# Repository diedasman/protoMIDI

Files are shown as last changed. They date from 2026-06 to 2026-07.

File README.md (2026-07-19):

# protoMIDI

## Sponsor

**THIS PROJECT IS SPONSORED BY [PCBWAY](https://www.pcbway.com/)**

protoMIDI is a compact DIY HID macropad with the control language of a small
MIDI controller. The current v1.1 design uses a custom PCB in a two-piece
enclosure with eight illuminated push buttons, two rotary encoders, a toggle,
a small utility push button, and an nRF52840 Pro Micro style controller.

> **Asset version:** The screenshots, renders, photographs, and GIFs in
> [`assets/`](./assets/) currently show v1.0 hardware. Updated v1.1 assets will
> be added later.

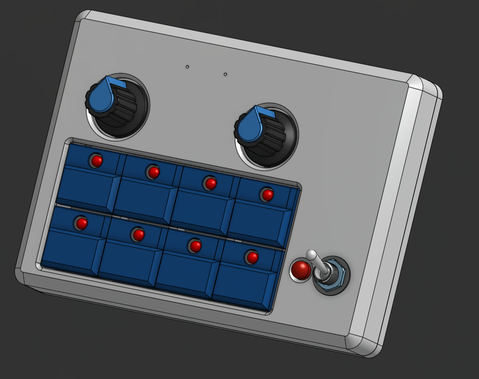
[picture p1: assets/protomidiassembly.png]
protoMIDI v1.0 assembly reference


Despite the controller-style hardware, protoMIDI currently targets ZMK keyboard
firmware. It presents as a keyboard/HID macropad, not as a USB MIDI or BLE MIDI
controller. DAW, transport, clip, track, or effects labels are keymap choices,
not a dedicated MIDI protocol layer.

## Status

v1.1 is the active design. Both manufacturing handoffs remain available:

| Version | Status | DFM pack |
| --- | --- | --- |
| v1.1 | Current | [hardware/protoMIDI-DFM-PACK-v1.1](./hardware/protoMIDI-DFM-PACK-v1.1/README.md) |
| v1.0 | Historical release | [hardware/protoMIDI-DFM-PACK-v1.0](./hardware/protoMIDI-DFM-PACK-v1.0/README.md) |

The Rev A prototype remains in [prototype](./prototype/README.md) as historical
reference for the earlier display-equipped build.

## v1.1 Update

v1.1 retains the v1.0 control layout and updates the manufacturing files:

- PCB silkscreen refinements and newly exported v1.1 Gerbers
- Increased enclosure wall thickness
- Increased USB-C connector clearance
- Increased switch clearance
- A slight angle added to the bottom enclosure
- A supported v1.1 ZMK firmware build with ZMK Studio over USB

The design scope remains:

- Custom PCB as the main electronics artifact
- 8x PB86-B1 illuminated momentary switches
- 2x EC11/PEC11R style rotary encoders with knobs
- 1x MTS-style toggle switch
- 1x 6 mm utility push button
- 1x nRF52840 Pro Micro style controller
- 1x single-cell LiPo battery connection
- Two-piece enclosure: top and bottom
- M2.5 mounting hardware with threaded inserts, matched to the CAD references

The local KiCad source folder, `hardware/protoMIDI-KiCAD/`, and local CAD
reference folder, `hardware/CAD/`, are intentionally ignored. The tracked
manufacturing handoffs are the versioned DFM packs.

## Images

All project-owned images below are v1.0 references.

| Bare PCB | PCB assembly |
| --- | --- |
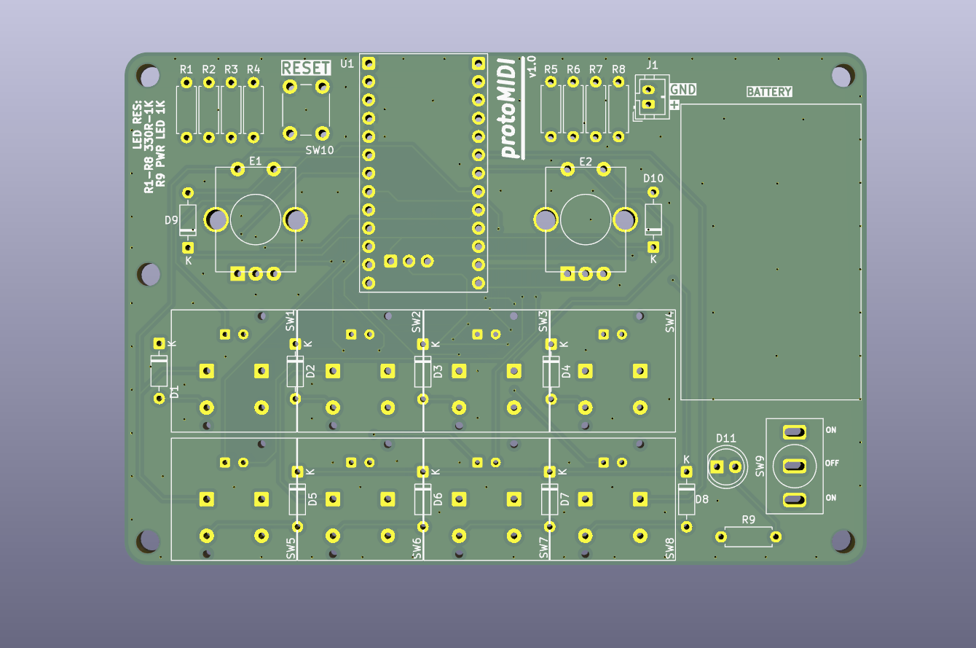
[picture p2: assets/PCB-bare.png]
protoMIDI v1.0 bare PCB
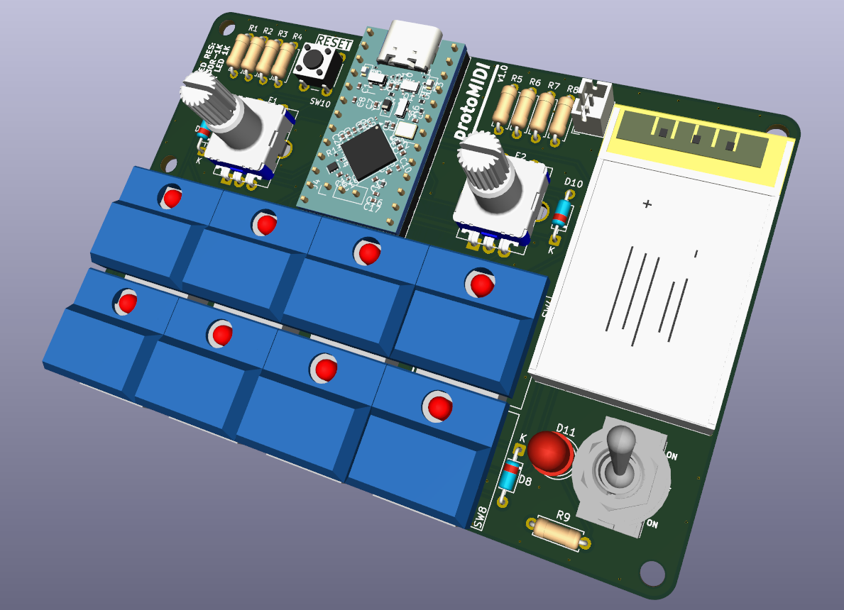
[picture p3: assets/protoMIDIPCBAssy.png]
protoMIDI v1.0 PCB assembly
|  |  |

| Front assembly | Back assembly |
| --- | --- |
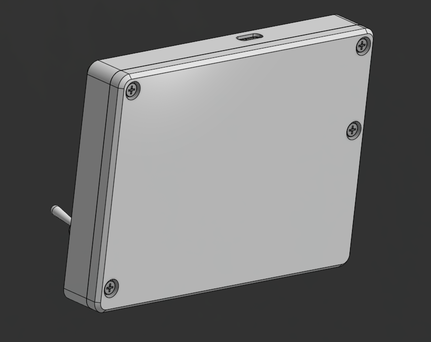
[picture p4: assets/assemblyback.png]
protoMIDI v1.0 back assembly
| protoMIDI v1.0 assembly |  |

| Front exploded view | Back exploded view |
| --- | --- |
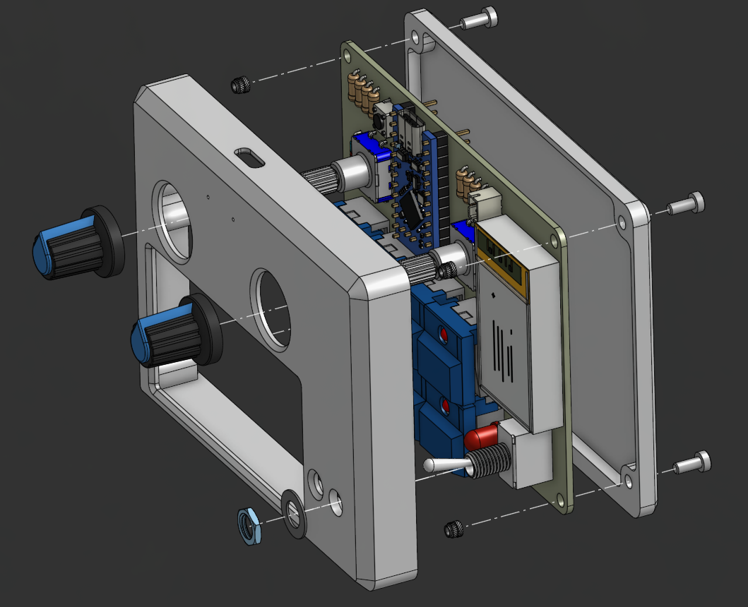
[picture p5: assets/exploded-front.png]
protoMIDI v1.0 front exploded view
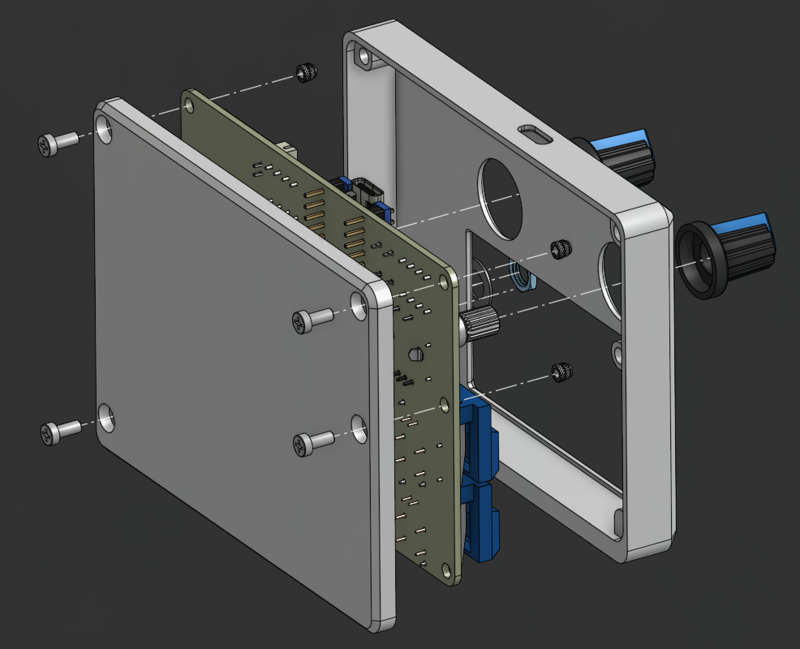
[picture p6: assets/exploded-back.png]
protoMIDI v1.0 back exploded view
|  |  |

Prototype media lives in [prototype](./prototype/README.md):

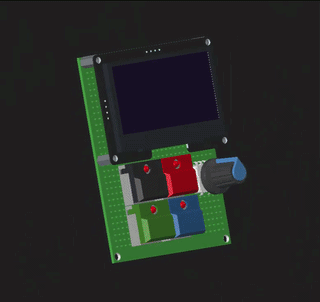
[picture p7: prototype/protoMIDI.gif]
protoMIDI prototype demo


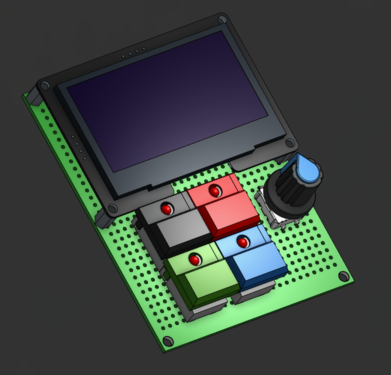
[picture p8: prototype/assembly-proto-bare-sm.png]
protoMIDI prototype assembly


## Hardware

Start with [hardware/README.md](./hardware/README.md) for version differences,
tracked exports, ignored source folders, and DFM pack links. Component source
notes live in [resources](./resources/README.md).

## Firmware

The supported v1.1 firmware lives in [firmware](./firmware/README.md). It targets
the `nice_nano_v2` compatible nRF52840 board and `protomidi` shield, includes
both encoders and all eight PB86 switches, and supports live keymap editing in
ZMK Studio over USB. The repository intentionally ships only this Studio build.

Build it from the repository root:

```sh
./firmware/build-local.sh
```

The ignored output is:

```text
firmware/build-out/protomidi-v1.1-studio-usb.uf2
```

The Rev A display-equipped firmware remains available in
[prototype/firmware](./prototype/firmware/README.md).

## Repository Layout

```text
assets/       Project-owned v1.0 visual references (v1.1 update pending)
firmware/     Supported v1.1 USB Studio ZMK build
hardware/     Versioned v1.0 and v1.1 DFM handoffs and hardware notes
prototype/    Rev A prototype firmware, CAD export, preview image, and demo GIF
resources/    Source references and component notes
```

Local-only ignored working areas:

```text
hardware/protoMIDI-KiCAD/     Active KiCad design source and BOM CSV
hardware/CAD/                 Local CAD assemblies and reference exports
firmware/builds/standard/     Optional local-only non-Studio configuration
firmware/build-out/           Firmware build output
prototype/firmware/build-out/ Prototype firmware build output
```

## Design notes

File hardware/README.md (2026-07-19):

# protoMIDI Hardware

This directory documents the protoMIDI custom PCB and two-piece enclosure. v1.1
is the current release; the original v1.0 manufacturing handoff remains
available for reproducibility.

## Manufacturing Handoffs

| Version | Status | Contents |
| --- | --- | --- |
| [v1.1 DFM pack](./protoMIDI-DFM-PACK-v1.1/README.md) | Current | v1.1 PCB Gerbers/drills and revised enclosure STEP/STL exports |
| [v1.0 DFM pack](./protoMIDI-DFM-PACK-v1.0/README.md) | Historical | Original PCB Gerbers/drills, enclosure STEP/STL exports, and top drawing DXF |

The packs are deliberately versioned rather than replacing the earlier
manufacturing release.

## v1.1 Changes

- Refined PCB silkscreen and exported a new v1.1 Gerber set
- Increased enclosure wall thickness
- Increased clearance around the USB-C connector
- Increased switch clearance
- Added a slight angle to the bottom enclosure
- Promoted the ZMK Studio USB firmware to the supported v1.1 build

## Hardware Scope

- Custom PCB with nRF52840 Pro Micro style controller footprint
- 8x PB86-B1 illuminated push buttons
- 2x EC11/PEC11R style rotary encoders
- 2x encoder knobs, referenced in the local enclosure assembly CAD
- 1x MTS-style toggle switch
- 1x 6 mm utility push button
- 1x LiPo battery connector
- Two-piece enclosure: top and bottom
- M2.5 mounting hardware with threaded inserts, referenced by the local CAD

The OLED display is prototype-only and is not part of v1.0 or v1.1.

## BOM

The electronic BOM is common to v1.0 and v1.1. Mechanical items are added from
the enclosure/CAD design. Copies of this table live in both DFM pack READMEs.

`R1-R8` are the illuminated switch LED current-limit resistors. `R9` is the
power/status LED current-limit resistor for `D11`.

| Qty | References | Value / Part | Description |
| ---: | --- | --- | --- |
| 1 | BT1 | Battery_Cell | Single-cell LiPo battery, KiCad footprint `Battery_LiPo_802540_800mAh` |
| 10 | D1-D10 | 1N4148 | Signal diodes for switch matrix |
| 1 | D11 | LED | 5 mm power/status indicator LED |
| 2 | E1,E2 | PEC11R-4215F-S0024 | EC11/PEC11R style vertical rotary encoders, 15 mm shaft |
| 1 | J1 | JST PH 1x02 | 2-pin vertical battery connector, 2.00 mm pitch |
| 8 | R1-R8 | 330 ohm | Through-hole resistors for illuminated switch LEDs |
| 1 | R9 | 680 ohm to 1 kOhm | Through-hole resistor for power/status LED `D11` |
| 8 | SW1-SW8 | PB86-B1 | Illuminated momentary push buttons |
| 1 | SW9 | SW_DPDT_x2 / MTS style | Vertical toggle switch |
| 1 | SW10 | SW_Push | 6 x 6 mm utility push button |
| 1 | U1 | nRF ProMicro | nRF52840 Pro Micro style controller module |
| 2 | ENC knobs | ROTARY_ENCODER_KNOB | Encoder knobs; see the local versioned enclosure assembly in `hardware/CAD/` for fit/details |
| 1 | Enclosure top | protoMIDI ENCLOSURE TOP | STEP/STL export in the selected versioned DFM pack |
| 1 | Enclosure bottom | protoMIDI ENCLOSURE BOTTOM | STEP/STL export in the selected versioned DFM pack |
| 4 | Mounting screws | EDDT-M2.5-L6 | M2.5 L6 screw reference; local CAD file `hardware/CAD/EDDT-M2.5-L6.step` |
| 4 | Threaded inserts | EMLZ-M2.5-L3 | M2.5 L3 threaded insert reference; local CAD file `hardware/CAD/EMLZ-M2.5-L3.step` |

## Media

> **Asset version:** The following project images show v1.0. They have not yet
> been regenerated for the v1.1 enclosure and silkscreen updates.

protoMIDI v1.0 PCB assembly

protoMIDI v1.0 bare PCB

protoMIDI v1.0 front exploded enclosure view

protoMIDI v1.0 back exploded enclosure view

## Source Boundary

The active KiCad source in `hardware/protoMIDI-KiCAD/` and CAD references in
`hardware/CAD/` are local working files and intentionally ignored. The tracked
public handoffs are the versioned DFM packs above.

## Prototype Reference

The Rev A prototype remains available for comparison:

- [Prototype overview](../prototype/README.md)
- [Prototype firmware](../prototype/firmware/README.md)
- [Prototype STEP assembly](../prototype/CAD/protoMIDI%20ASSEMBLY.step)

Prototype assembly preview

Prototype demo GIF

## Component References

Useful component notes remain in [resources](../resources/README.md). Some notes
are historical prototype references; the display page is not part of v1.0 or
v1.1.

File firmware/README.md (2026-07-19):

# protoMIDI v1.1 Firmware

This directory contains the supported protoMIDI v1.1 ZMK firmware. It targets
the nRF52840 Pro Micro-compatible `nice_nano_v2` board and the `protomidi`
shield. The custom PCB has no display.

The supported build includes live keymap editing through ZMK Studio over USB.
VIA is a QMK configurator and is not used by this ZMK project.

Only the `studio-usb` configuration is included in the repository. The original
non-Studio configuration is intentionally local-only and excluded by
`.gitignore`, so the public firmware has one supported version.

## Build and Flash

From the repository root, run:

```sh
./firmware/build-local.sh
```

The script builds only the supported Studio configuration and writes one
ignored UF2 file:

```text
firmware/build-out/protomidi-v1.1-studio-usb.uf2
```

The script uses the official ZMK Docker build image. The first build downloads
the ZMK and Zephyr dependencies into the ignored `firmware/.zmk/` workspace;
later builds reuse that workspace.

Double-tap reset on the controller to enter its UF2 bootloader, then copy the
UF2 file onto the mounted bootloader drive.

## USB Keymap Editing

Flash `protomidi-v1.1-studio-usb.uf2`, connect protoMIDI over USB, and open
[ZMK Studio](https://zmk.studio/) in Chrome/Edge or its native app. This build
starts Studio unlocked because configuration access already requires a physical
USB connection.

Studio can edit the two encoder push switches and the eight illuminated push
buttons. Encoder rotation remains defined in `protomidi.keymap`, matching ZMK
Studio's current encoder limitation.

The tracked source configuration lives in:

```text
firmware/builds/studio-usb/config/
```

## PCB Pinout

The switch matrix is `col2row`.

| Signal | nRF52840 GPIO |
| --- | --- |
| ROW0, ROW1, ROW2 | P1.01, P1.02, P1.07 |
| COL0, COL1, COL2, COL3 | P0.02, P1.11, P0.29, P0.31 |
| ENC1 A, B | P1.15, P1.13 |
| ENC2 A, B | P0.10, P0.09 |
| LED1-LED8 | P0.17, P0.20, P0.22, P0.24, P1.00, P0.11, P1.04, P1.06 |

The LEDs run in four vertical pairs: LED1+LED5, LED2+LED6, LED3+LED7, and
LED4+LED8. Each pair is on for 250 ms, giving a one-second chase, followed by
one second with all LEDs off before the chase restarts.

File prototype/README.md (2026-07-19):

# protoMIDI Prototype

This folder contains the Rev A protoMIDI prototype. It is the earlier
display-equipped build used to prove the physical controls, ZMK firmware, CAD
assembly, and HID behavior before the v1.0 custom PCB release.

The prototype is historical reference. The active design is v1.1 in
[../hardware](../hardware/README.md).

protoMIDI prototype demo

## Contents

| Path | Purpose |
| --- | --- |
| [firmware](./firmware/README.md) | ZMK user config and local build script for the Rev A prototype |
| [CAD/protoMIDI ASSEMBLY.step](./CAD/protoMIDI%20ASSEMBLY.step) | Exported STEP assembly for the bare prototype build |
| [assembly-proto-bare-sm.png](./assembly-proto-bare-sm.png) | Prototype assembly preview image |
| [protoMIDI.gif](./protoMIDI.gif) | Prototype demo media used by older docs |

## Prototype Hardware

The Rev A prototype uses:

- nRF52840 Pro Micro style development board compatible with `nice_nano_v2`
- Four PB86-B1 illuminated momentary switches
- One EC11-style rotary encoder with push switch
- 2.42 inch 128x64 SSD1309 I2C OLED display
- 3.7 V LiPo battery
- ZMK firmware configured as a HID keyboard/macropad

The PB86 LEDs are hardwired to 3V3 in the prototype. Firmware does not dim them,
turn them off individually, or represent per-button LED state.

protoMIDI prototype assembly

## Firmware

Build from the repository root:

```sh
./prototype/firmware/build-local.sh
```

The default firmware output is ignored and written to:

```text
prototype/firmware/build-out/protomidi-nice_nano_v2.uf2
```

Double-tap reset on the nRF52840 board to enter the UF2 bootloader, then copy the
generated `.uf2` file to the mounted bootloader drive.

See [prototype/firmware/README.md](./firmware/README.md) for firmware details,
dependencies, pinout notes, and manual build commands.

## Relationship To v1.1

The v1.0 release removed the display, moved to a custom PCB, increased the
switch count to eight, increased the encoder count to two, and added tracked
enclosure DFM exports. v1.1 refines that PCB silkscreen and enclosure and adds
the supported ZMK Studio firmware build. Use this folder for old behavior checks
and migration comparisons.

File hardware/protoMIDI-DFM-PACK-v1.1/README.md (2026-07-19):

# protoMIDI v1.1 DFM Pack

This folder is the current manufacturing handoff for protoMIDI. It contains the
v1.1 PCB fabrication files and revised two-piece enclosure exports. The
[v1.0 DFM pack](../protoMIDI-DFM-PACK-v1.0/README.md) remains available as the
original release.

## v1.1 Changes

- Refined PCB silkscreen and exported a new Gerber set
- Increased enclosure wall thickness
- Increased USB-C connector clearance
- Increased switch clearance
- Added a slight angle to the bottom enclosure

The supported firmware paired with this release is the
[v1.1 ZMK Studio USB build](../../firmware/README.md).

## Files

| Path | Contents |
| --- | --- |
| [PCB-GERBERS](./PCB-GERBERS/) | v1.1 PCB copper, mask, paste, silkscreen, edge cuts, PTH drill, and NPTH drill files |
| [ENCLOSURE](./ENCLOSURE/) | Revised enclosure top and bottom as STEP and STL |

Enclosure exports:

- [protoMIDI ENCLOSURE TOP v1.1.step](./ENCLOSURE/protoMIDI%20ENCLOSURE%20TOP%20v1.1.step)
- [protoMIDI ENCLOSURE TOP v1.1.stl](./ENCLOSURE/protoMIDI%20ENCLOSURE%20TOP%20v1.1.stl)
- [protoMIDI ENCLOSURE BOTTOM v1.1.step](./ENCLOSURE/protoMIDI%20ENCLOSURE%20BOTTOM%20v1.1.step)
- [protoMIDI ENCLOSURE BOTTOM v1.1.stl](./ENCLOSURE/protoMIDI%20ENCLOSURE%20BOTTOM%20v1.1.stl)

The KiCad source project and local CAD reference files remain ignored in
`hardware/protoMIDI-KiCAD/` and `hardware/CAD/`.

## BOM

The electronic BOM is unchanged from v1.0; v1.1 changes the PCB silkscreen and
enclosure geometry.

| Qty | References | Value / Part | Description |
| ---: | --- | --- | --- |
| 1 | BT1 | Battery_Cell | Single-cell LiPo battery, KiCad footprint `Battery_LiPo_802540_800mAh` |
| 10 | D1-D10 | 1N4148 | Signal diodes for switch matrix |
| 1 | D11 | LED | 5 mm power/status indicator LED |
| 2 | E1,E2 | PEC11R-4215F-S0024 | EC11/PEC11R style vertical rotary encoders, 15 mm shaft |
| 1 | J1 | JST PH 1x02 | 2-pin vertical battery connector, 2.00 mm pitch |
| 8 | R1-R8 | 330 ohm | Through-hole resistors for illuminated switch LEDs |
| 1 | R9 | 680 ohm to 1 kOhm | Through-hole resistor for power/status LED `D11` |
| 8 | SW1-SW8 | PB86-B1 | Illuminated momentary push buttons |
| 1 | SW9 | SW_DPDT_x2 / MTS style | Vertical toggle switch |
| 1 | SW10 | SW_Push | 6 x 6 mm utility push button |
| 1 | U1 | nRF ProMicro | nRF52840 Pro Micro style controller module |
| 2 | ENC knobs | ROTARY_ENCODER_KNOB | Encoder knobs; see local v1.1 CAD assembly for fit/details |
| 1 | Enclosure top | protoMIDI ENCLOSURE TOP v1.1 | Revised STEP/STL export in `ENCLOSURE/` |
| 1 | Enclosure bottom | protoMIDI ENCLOSURE BOTTOM v1.1 | Revised STEP/STL export in `ENCLOSURE/` |
| 4 | Mounting screws | EDDT-M2.5-L6 | M2.5 L6 screw reference |
| 4 | Threaded inserts | EMLZ-M2.5-L3 | M2.5 L3 threaded insert reference |

## Visual References

> **Asset version:** The repository images currently show v1.0. They are useful
> as general assembly references but do not show the v1.1 silkscreen or
> enclosure geometry. Updated screenshots will be added later.

protoMIDI v1.0 assembly reference

protoMIDI v1.0 PCB assembly reference

protoMIDI v1.0 exploded enclosure reference

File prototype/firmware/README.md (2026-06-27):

# protoMIDI Firmware

This directory is a nested ZMK user config inside the larger protoMIDI hardware
repo. The preferred build path is local, so builders can compile firmware from
the open-source files in this repository entirely on their own machine.

## Table of Contents

- [Hardware Support](#hardware-support)
- [Pinout](#pinout)
- [Quick Build](#quick-build)
- [Dependencies](#dependencies)
- [Manual Build Sketch](#manual-build-sketch)

The firmware target is the Rev A bare controller:

- Board: `nice_nano_v2`
- Shield: `protomidi`
- Inputs: 2x3 key matrix with five populated positions
- Encoder: one EC11-compatible quadrature encoder
- Display: 2.42 inch 128x64 SSD1309 OLED over I2C using Zephyr's SSD1306-compatible driver

## Hardware Support

This build is the protoMIDI firmware baseline: switches, encoder, OLED display,
USB HID, and Bluetooth HID. Pin assignments match the Rev A pinout documented
below.

Supported:

- `nice_nano_v2` compatible nRF52840 board target
- 2x3 GPIO switch matrix
- Four PB86 momentary buttons
- Encoder push switch as the fifth matrix key
- One unused matrix position at row 1, column 2
- `col2row` matrix diode direction
- EC11-style rotary encoder on separate A/B GPIOs
- 128x64 SSD1309 OLED on I2C
- Custom animated monochrome protoMIDI OLED graphic
- USB HID keyboard
- Bluetooth HID keyboard through the selected ZMK board target
- UF2 firmware output for drag-and-drop flashing

Default key behavior:

| Control | Binding |
| --- | --- |
| PB86-1 | Play/pause |
| PB86-2 | none |
| PB86-3 | Previous track |
| PB86-4 | Next track |
| Encoder push | Mute |
| Encoder clockwise | Volume up |
| Encoder counter-clockwise | Volume down |

The PB86 LEDs are hardwired to 3V3. Firmware does not provide LED/backlight or
per-button LED state control.

The OLED pin choice is intentional for this build: the shield overrides the
`nice_nano_v2` I2C defaults and places the SSD1309 module on `P1.06`/`P1.04`.

## Pinout

This is the firmware pinout for the Rev A bare controller.

ZMK target:

- Board target: `nice_nano_v2`
- Shield: `protomidi`
- Firmware path: `prototype/firmware/config/boards/shields/protomidi`

Matrix diode direction: `col2row`

| Matrix position | Function | GPIO label | ZMK devicetree pin |
| --- | --- | --- | --- |
| Row 0 | PB86-1/PB86-2 encoder push row | `115` | `&gpio1 15` |
| Row 1 | PB86-3/PB86-4 row | `011` | `&gpio0 11` |
| Col 0 | PB86-1/PB86-3 | `002` | `&gpio0 02` |
| Col 1 | PB86-2/PB86-4/unused column | `111` | `&gpio1 11` |
| Col 2 | Encoder push column | `029` | `&gpio0 29` |

Logical matrix:

| | COL0 | COL1 | COL2 |
| --- | --- | --- | --- |
| ROW0 | PB86-1 | PB86-2 | ENC_PUSH |
| ROW1 | PB86-3 | PB86-4 | unused |

Encoder:

| Function | GPIO label | ZMK devicetree pin |
| --- | --- | --- |
| Encoder A | `024` | `&gpio0 24` |
| Encoder B | `022` | `&gpio0 22` |
| Encoder common | GND | GND |

OLED display:

| Function | GPIO label | ZMK devicetree pin |
| --- | --- | --- |
| OLED SDA | `106` | `NRF_PSEL(TWIM_SDA, 1, 6)` |
| OLED SCL | `104` | `NRF_PSEL(TWIM_SCL, 1, 4)` |

The shield overlay overrides the `nice_nano_v2` I2C defaults and uses
`P1.06`/`P1.04` for the OLED.

## Quick Build

Install Docker, then run this from the repository root:

```sh
./prototype/firmware/build-local.sh
```

The default output path is:

```text
prototype/firmware/build-out/protomidi-nice_nano_v2.uf2
```

Double-tap reset on the nRF52840 board to enter the UF2 bootloader, then copy
that `.uf2` file to the mounted bootloader drive.

The build script also accepts explicit board and shield arguments:

```sh
./prototype/firmware/build-local.sh nice_nano_v2 protomidi
```

The script keeps the ZMK checkout in `prototype/firmware/.zmk/workspace`, which
is ignored by git. The first run downloads the ZMK and Zephyr dependencies, so
it can take a while. Later runs reuse that workspace.

## Dependencies

Default path:

- Docker
- Internet access for dependency downloads

The script uses the official `zmkfirmware/zmk-build-arm:stable` container image,
so builders do not need to install Zephyr SDK, `west`, or Python packages on the
host system.

## Manual Build Sketch

If you already maintain your own ZMK/Zephyr toolchain, build with:

```sh
west build -s zmk/app -b nice_nano_v2 -- \
  -DSHIELD=protomidi \
  -DZMK_CONFIG=/absolute/path/to/protoMIDI/prototype/firmware/config
```

The build command above matches the tracked `nice_nano_v2` and `protomidi`
configuration.

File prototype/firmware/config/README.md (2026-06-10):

# ZMK Config

## Table of Contents

- [Configuration](#configuration)
- [Files](#files)

`boards/shields/protomidi` contains the protoMIDI shield definition.

## Configuration

- The controller uses ZMK's `nice_nano_v2` board target.
- Pin labels in the hardware docs are nRF GPIO labels: `002` means `P0.02`,
  `115` means `P1.15`, and so on.
- Matrix diode direction is `col2row`.
- OLED display support is enabled through Zephyr's SSD1306-compatible driver for
  the 128x64 SSD1309 module.
- PB86 LED/backlight and per-button LED state control are not configured because
  the PB86 LEDs are hardwired to 3V3.

## Files

- `boards/shields/protomidi/protomidi.overlay`
- `boards/shields/protomidi/protomidi.keymap`
- `boards/shields/protomidi/protomidi.conf`
- `boards/shields/protomidi/custom_status_screen.c`
- `west.yml`

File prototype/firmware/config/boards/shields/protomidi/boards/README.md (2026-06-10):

# Board-Specific Overlay Directory

## Table of Contents

- [Purpose](#purpose)
- [Tracked Board Target](#tracked-board-target)

## Purpose

This directory is available for board-specific shield overlays. The tracked Rev
A build uses the base `protomidi.overlay` file in the parent shield directory.

## Tracked Board Target

The firmware build target is `nice_nano_v2`. The base shield overlay uses direct
nRF GPIO controller references so the pinout remains easy to compare with the
physical board silkscreen.

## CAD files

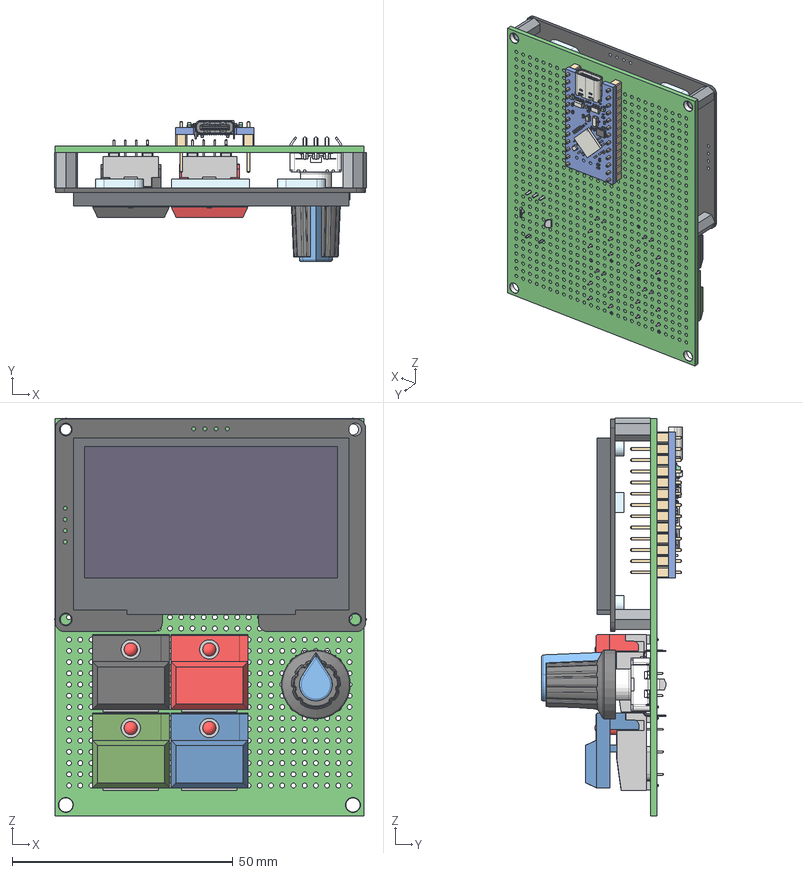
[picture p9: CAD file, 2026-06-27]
prototype/CAD/protoMIDI ASSEMBLY.step
70.7 x 32.0 x 90.1 mm
C_0402_1005Metric_14
USB_C_Receptacle_GCT_USB4105-xx-A_16P_TopMnt_Horizontal030
R_0201_0603Metric_6
SOT-23
USB_C_Receptacle_GCT_USB4105-xx-A_16P_TopMnt_Horizontal
C_0402_1005Metric_3
L_0402_1005Metric_1
Adafruit PB86-1AR v003
L_0402_1005Metric_3
USB_C_Receptacle_GCT_USB4105-xx-A_16P_TopMnt_Horizontal025
Adafruit PB86-1AR v1
USB_C_Receptacle_GCT_USB4105-xx-A_16P_TopMnt_Horizontal020
ROTARY_ENCODER_KNOB x 2
USB_C_Receptacle_GCT_USB4105-xx-A_16P_TopMnt_Horizontal034
R_0201_0603Metric_1
R_0201_0603Metric_2
Adafruit PB86-1AR v001
C_0201_0603Metric
USB_C_Receptacle_GCT_USB4105-xx-A_16P_TopMnt_Horizontal003
Universal_board_70x90mm_31x26-prt795
promicro_PCB
USB_C_Receptacle_GCT_USB4105-xx-A_16P_TopMnt_Horizontal001
USB_C_Receptacle_GCT_USB4105-xx-A_16P_TopMnt_Horizontal006
USB_C_Receptacle_GCT_USB4105-xx-A_16P_TopMnt_Horizontal026
Adafruit PB86-1AR v024
USB_C_Receptacle_GCT_USB4105-xx-A_16P_TopMnt_Horizontal021
R_0201_0603Metric
C_0402_1005Metric_9
SOT-666
Adafruit PB86-1AR v015
USB_C_Receptacle_GCT_USB4105-xx-A_16P_TopMnt_Horizontal031
C_0402_1005Metric_1
Adafruit PB86-1AR v028
USB_C_Receptacle_GCT_USB4105-xx-A_16P_TopMnt_Horizontal035
USB_C_Receptacle_GCT_USB4105-xx-A_16P_TopMnt_Horizontal023
PinHeader_1x13_P2.54mm_Vertical
Adafruit PB86-1AR v016
C_0402_1005Metric_16
USB_C_Receptacle_GCT_USB4105-xx-A_16P_TopMnt_Horizontal022
USB_C_Receptacle_GCT_USB4105-xx-A_16P_TopMnt_Horizontal024
OLED 2.42 V1.1 SSD1309
Adafruit PB86-1AR v030
C_0402_1005Metric_13
SOT-23-5
R_0201_0603Metric_8
L_0402_1005Metric_2
USB_C_Receptacle_GCT_USB4105-xx-A_16P_TopMnt_Horizontal002
R_0201_0603Metric_5
Universal_board_70x90mm_31x26-prt0
USB_C_Receptacle_GCT_USB4105-xx-A_16P_TopMnt_Horizontal004
R_0201_0603Metric_4
R_0402_1005Metric_2
C_0201_0603Metric_2
C_0402_1005Metric_6
Adafruit PB86-1AR v006
R_0201_0603Metric_3
USB_C_Receptacle_GCT_USB4105-xx-A_16P_TopMnt_Horizontal029
C_0201_0603Metric_1
PinHeader_1x13_P2.54mm_Vertical_1
Universal_board_70x90mm_31x26-prt794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

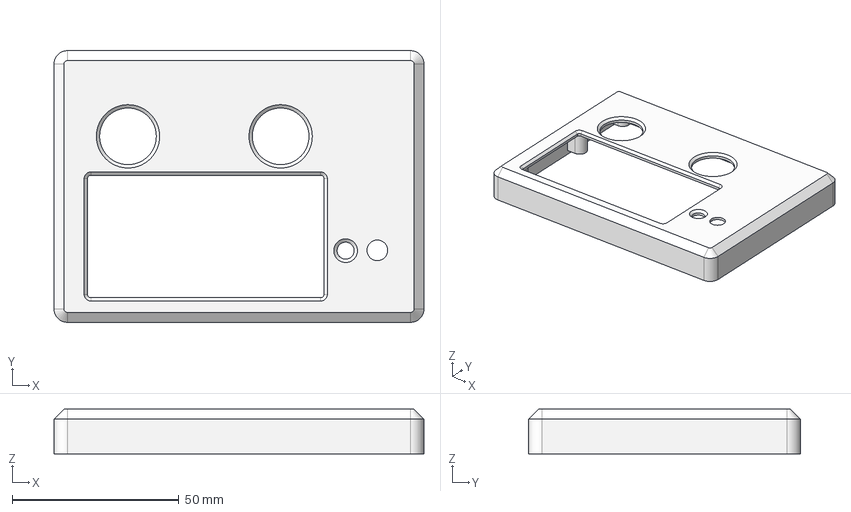
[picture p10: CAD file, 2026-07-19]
hardware/protoMIDI-DFM-PACK-v1.1/ENCLOSURE/protoMIDI ENCLOSURE TOP v1.1.step
111.0 x 81.5 x 13.5 mm

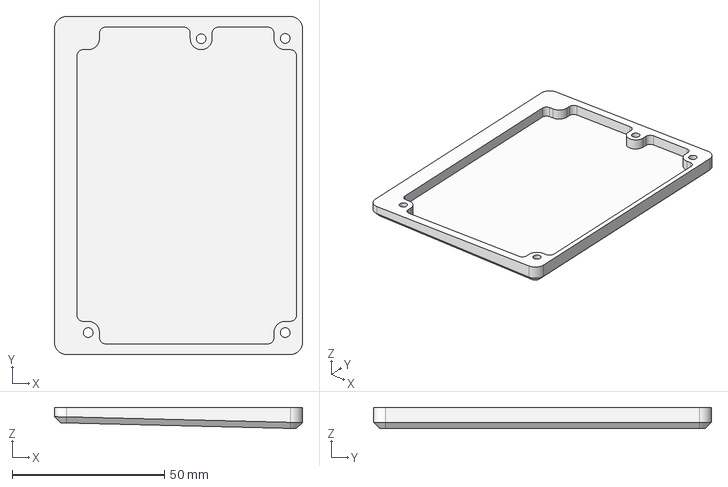
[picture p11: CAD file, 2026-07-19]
hardware/protoMIDI-DFM-PACK-v1.1/ENCLOSURE/protoMIDI ENCLOSURE BOTTOM v1.1.step
81.5 x 111.0 x 6.95 mm

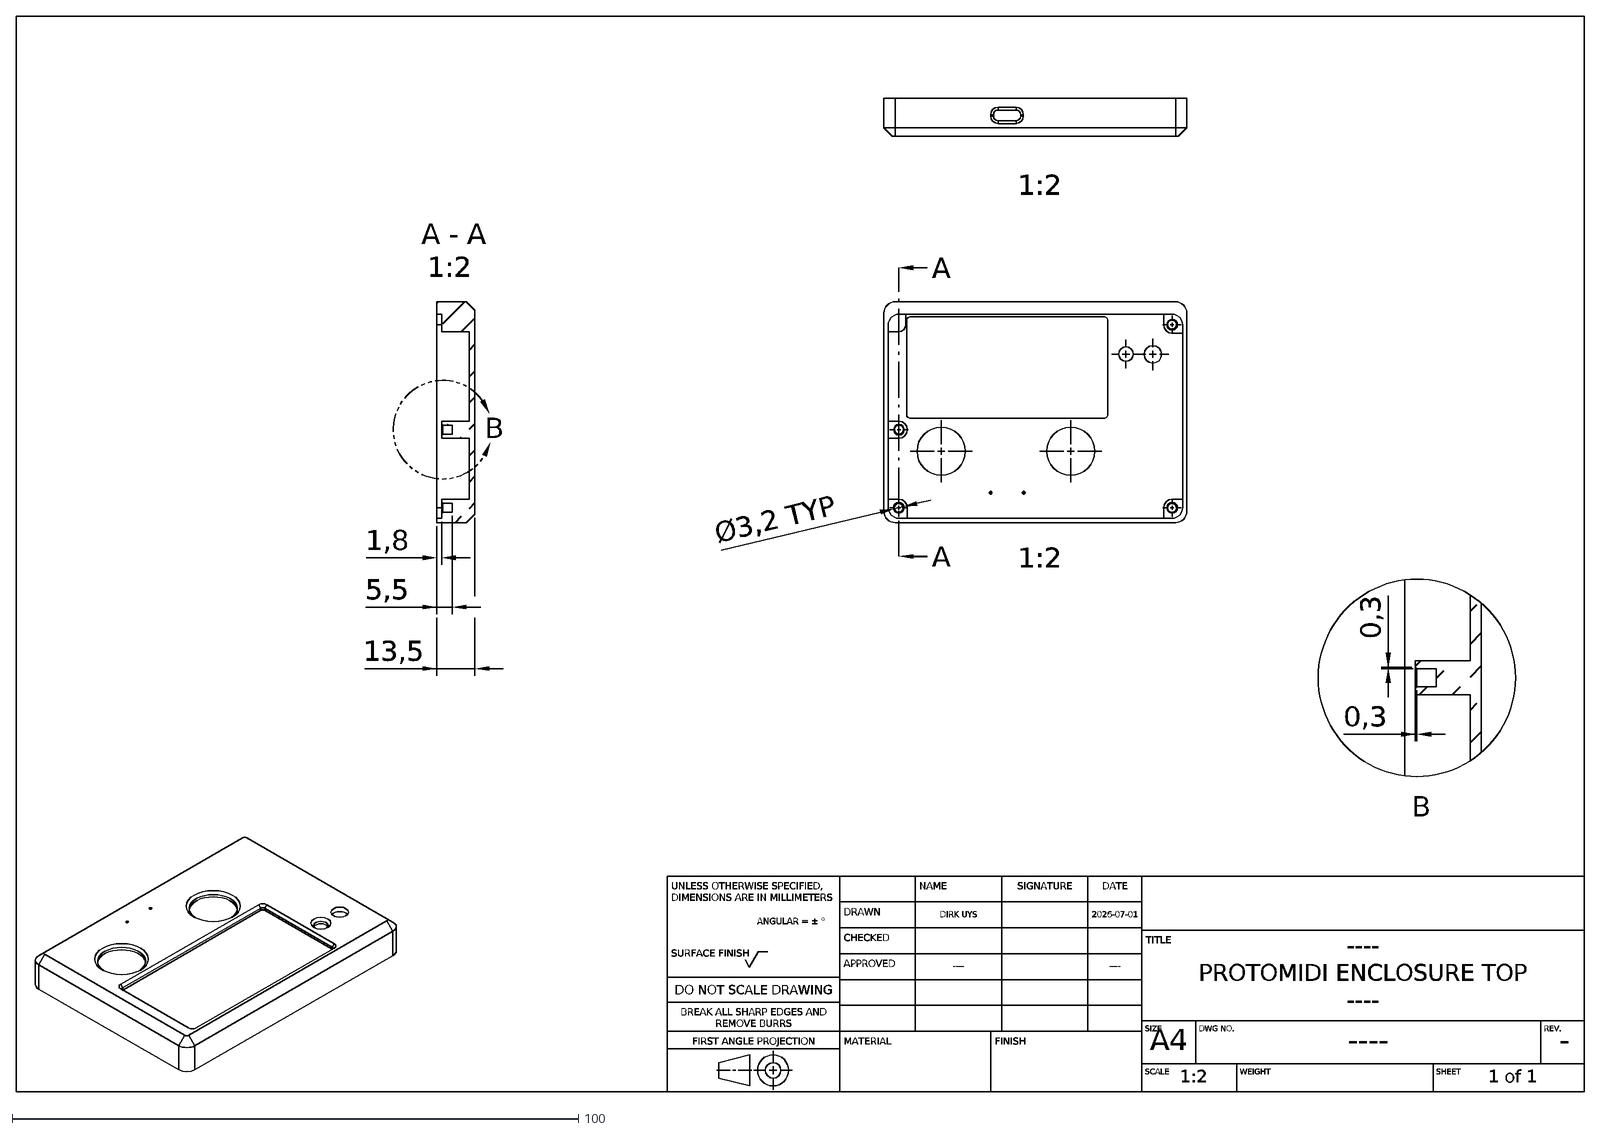
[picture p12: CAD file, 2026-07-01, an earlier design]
hardware/protoMIDI-DFM-PACK-v1.0/ENCLOSURE/protoMIDI ENCLOSURE TOP DRAWING.dxf
UNLESS OTHERWISE SPECIFIED, DIMENSIONS ARE IN MILLIMETERS
ANGULAR = ± °
SURFACE FINISH
DO NOT SCALE DRAWING
BREAK ALL SHARP EDGES AND REMOVE BURRS
FIRST ANGLE PROJECTION
SIGNATURE
NAME
DATE
DRAWN
DIRK UYS
2026-07-01
CHECKED
APPROVED
----
MATERIAL
FINISH
TITLE
PROTOMIDI ENCLOSURE TOP
SIZE
A4
DWG NO.
REV.
-
SCALE
1:2
WEIGHT
SHEET
1 of 1
A
A - A 1:2
5,5
13,5
1,8
Ø3,2 TYP
B
0,3

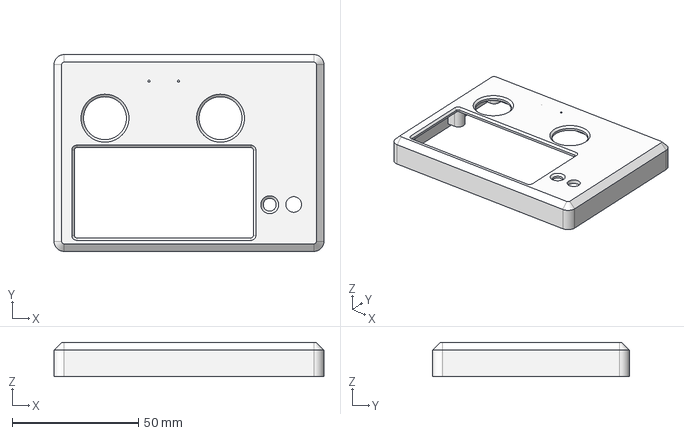
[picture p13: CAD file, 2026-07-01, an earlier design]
hardware/protoMIDI-DFM-PACK-v1.0/ENCLOSURE/protoMIDI ENCLOSURE TOP.step
107.0 x 78.0 x 13.5 mm

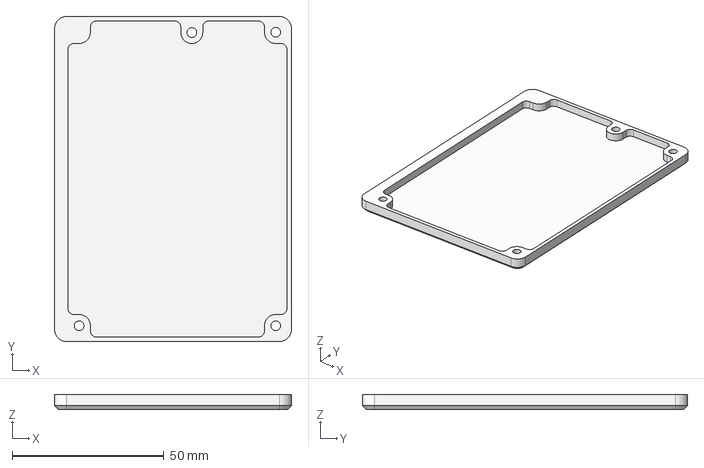
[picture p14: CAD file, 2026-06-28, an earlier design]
hardware/protoMIDI-DFM-PACK-v1.0/ENCLOSURE/protoMIDI ENCLOSURE BOTTOM.step
78.0 x 107.0 x 5.00 mm

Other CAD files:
hardware/protoMIDI-DFM-PACK-v1.0/ENCLOSURE/protoMIDI ENCLOSURE BOTTOM.stl
hardware/protoMIDI-DFM-PACK-v1.0/ENCLOSURE/protoMIDI ENCLOSURE TOP.stl
hardware/protoMIDI-DFM-PACK-v1.1/ENCLOSURE/protoMIDI ENCLOSURE BOTTOM v1.1.stl
hardware/protoMIDI-DFM-PACK-v1.1/ENCLOSURE/protoMIDI ENCLOSURE TOP v1.1.stl

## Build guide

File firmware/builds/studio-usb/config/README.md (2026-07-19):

# USB Studio ZMK Config

This is the supported protoMIDI v1.1 firmware configuration. It provides
runtime keymap editing through ZMK Studio over USB. Its physical layout contains
the two encoder push switches and eight illuminated push buttons; encoder
rotation bindings remain defined in the keymap source.

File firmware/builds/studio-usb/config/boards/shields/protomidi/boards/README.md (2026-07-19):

# Board support

The protoMIDI v1.1 shield is built with the `nice_nano_v2` ZMK board target,
which supports the nRF52840 Pro Micro-compatible controller footprint used on
the PCB.

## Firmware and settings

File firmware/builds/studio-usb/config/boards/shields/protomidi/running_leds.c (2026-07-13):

#include <zephyr/device.h>
#include <zephyr/drivers/gpio.h>
#include <zephyr/init.h>
#include <zephyr/kernel.h>

#define LED_PAIR_MS 250
#define LED_PAUSE_MS 1000
#define LED_COUNT 8
#define LED_COLUMN_COUNT 4

static const struct gpio_dt_spec leds[LED_COUNT] = {
    GPIO_DT_SPEC_GET(DT_NODELABEL(led1), gpios),
    GPIO_DT_SPEC_GET(DT_NODELABEL(led2), gpios),
    GPIO_DT_SPEC_GET(DT_NODELABEL(led3), gpios),
    GPIO_DT_SPEC_GET(DT_NODELABEL(led4), gpios),
    GPIO_DT_SPEC_GET(DT_NODELABEL(led5), gpios),
    GPIO_DT_SPEC_GET(DT_NODELABEL(led6), gpios),
    GPIO_DT_SPEC_GET(DT_NODELABEL(led7), gpios),
    GPIO_DT_SPEC_GET(DT_NODELABEL(led8), gpios),
};

static uint8_t active_column;
static bool pause_after_cycle;

static void advance_leds(struct k_work *work);

K_WORK_DELAYABLE_DEFINE(led_work, advance_leds);

static void advance_leds(struct k_work *work) {
    ARG_UNUSED(work);

    if (pause_after_cycle) {
        for (size_t led = 0; led < LED_COUNT; led++) {
            gpio_pin_set_dt(&leds[led], false);
        }

        pause_after_cycle = false;
        active_column = 0;
        k_work_schedule(&led_work, K_MSEC(LED_PAUSE_MS));
        return;
    }

    for (size_t led = 0; led < LED_COUNT; led++) {
        bool is_active = led == active_column || led == active_column + LED_COLUMN_COUNT;
        gpio_pin_set_dt(&leds[led], is_active);
    }

    if (active_column == LED_COLUMN_COUNT - 1) {
        pause_after_cycle = true;
    } else {
        active_column++;
    }

    k_work_schedule(&led_work, K_MSEC(LED_PAIR_MS));
}

static int protomidi_running_leds_init(void) {
    for (size_t led = 0; led < LED_COUNT; led++) {
        if (!gpio_is_ready_dt(&leds[led])) {
            return -ENODEV;
        }

        int err = gpio_pin_configure_dt(&leds[led], GPIO_OUTPUT_INACTIVE);
        if (err != 0) {
            return err;
        }
    }

    advance_leds(NULL);
    return 0;
}

SYS_INIT(protomidi_running_leds_init, APPLICATION, CONFIG_APPLICATION_INIT_PRIORITY);

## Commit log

2026-05-16 Add README for PB86-B1 switch with specifications and resources
2026-05-16 The current firmware build is a Rev A input bring-up build. Hardware-wise it supports:
    Controller board: nice_nano_v2 ZMK board target
    Shield: protomidi
    Switch matrix: 3 rows x 2 columns
    Populated key positions: 5 total
    PB86 button 1
    PB86 button 2
    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
2026-05-16 Update README files for protoMIDI: enhance descriptions and add current hardware support; restore switch reference documentation
2026-06-06 Update README and ToDo: document Rev A build status, firmware scope, and known limitations; add reset switch task
2026-06-12 Replace assembly image with new GIF and remove outdated PNG
2026-06-27 Refactor hardware documentation for v1.0 update
    - Updated README.md to reflect the transition from Rev A to v1.0 hardware, including changes in PCB design, switch and encoder counts, and removal of the OLED display.
    - Added sections for Status, Repository Boundary, v1.0 Hardware Direction, DFM Handoff, and Component References.
    - Removed obsolete sections related to the Rev A configuration, BOM, assembly preview, matrix, encoder, OLED display, and power.
    - Deleted unused images: assembly-proto-bare-sm.png and protoMIDI.gif.
2026-06-27 Add protoMIDI firmware and build scripts
    - Introduced README.md for protoMIDI firmware with hardware support, pinout, and build instructions.
    - Created build-local.sh script for building firmware using Docker.
    - Added ZMK configuration files for protoMIDI shield, including overlays, keymaps, and custom status screen.
    - Implemented Kconfig settings for protoMIDI features and dependencies.
    - Included necessary source files for OLED display and encoder functionality.
    - Added west.yml for managing ZMK dependencies.
    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
    [protoMIDI ASSEMBLY.step]
2026-06-28 Refactor code structure for improved readability and maintainability
    [protoMIDI ENCLOSURE BOTTOM.step, protoMIDI ENCLOSURE BOTTOM.stl, protoMIDI ENCLOSURE TOP.step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]
2026-07-01 Updated Enclosure Top thread insert holes
    [protoMIDI ENCLOSURE TOP.step, protoMIDI ENCLOSURE TOP.stl]
2026-07-01 added dxf drawing for enclosure top
    [protoMIDI ENCLOSURE BOTTOM.step, protoMIDI ENCLOSURE BOTTOM.stl, protoMIDI ENCLOSURE TOP DRAWING.dxf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]
2026-07-03 updated files
    [protoMIDI-KiCAD-B_Cu.gbl, protoMIDI-KiCAD-B_Mask.gbs, protoMIDI-KiCAD-B_Paste.gbp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]
2026-07-17 Refactor protoMIDI firmware build process and configuration
    - Updated build-local.sh to support building both standard and studio-usb firmware variants.
    - Removed deprecated protoMIDI configuration files and directories.
    - Added new configuration files for standard and studio-usb builds, including Kconfig, overlays, and keymaps.
    - Introduced README files for both build configurations to clarify usage and features.
    - Implemented runtime keymap editing for the studio-usb build, enhancing user experience.
    - Ensured compatibility with the nice_nano_v2 board target and updated GPIO configurations for LED handling.
2026-07-19 Add protoMIDI v1.1 DFM Pack with updated PCB and enclosure files
    - Introduced new NPTH and PTH drill files for v1.1 in the PCB-GERBERS directory.
    - Added README.md detailing changes in v1.1, including PCB refinements and enclosure modifications.
    - Updated BOM to reflect unchanged electronic components while noting changes in PCB silkscreen and enclosure geometry.
    [protoMIDI ENCLOSURE BOTTOM v1.1.step, protoMIDI ENCLOSURE BOTTOM v1.1.stl, protoMIDI ENCLOSURE BOTTOM.step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]
